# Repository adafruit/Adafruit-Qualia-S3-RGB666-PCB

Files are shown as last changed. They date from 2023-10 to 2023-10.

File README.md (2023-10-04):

## Adafruit Qualia ESP32-S3 for TTL RGB-666 Displays PCB

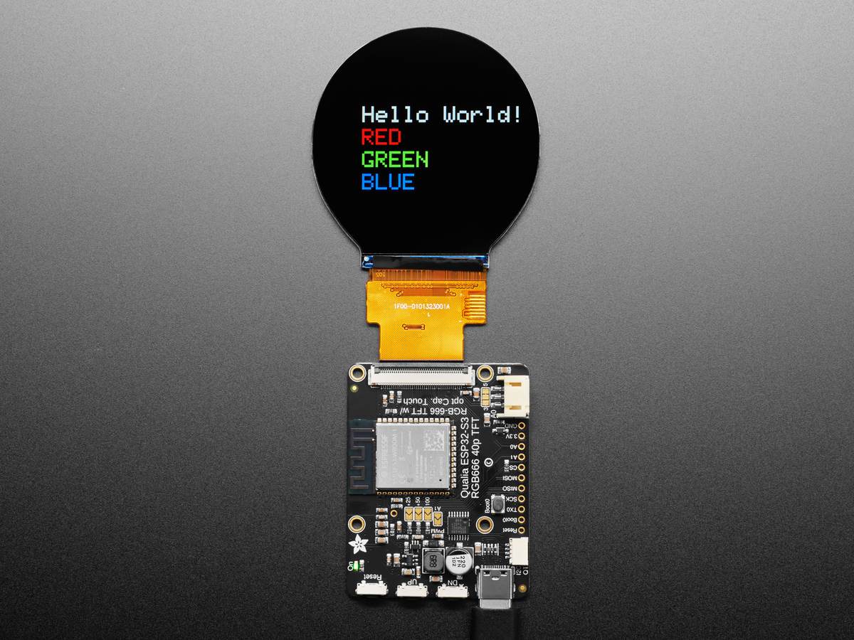
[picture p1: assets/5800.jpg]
<a href="http://www.adafruit.com/products/5800"><br/>
Click here to purchase one from the Adafruit shop</a>

PCB files for the Adafruit Qualia ESP32-S3 for TTL RGB-666 Displays.

Format is EagleCAD schematic and board layout
* https://www.adafruit.com/product/5800

### Description

There's a few things everyone loves: ice cream, kittens, and honkin' large TFT screens. We're no strangers to small TFT's - [from our itsy 1.14" color display](https://www.adafruit.com/search?q=1.14+tft) that graces many-a-TFT-Feather to [our fancy 3.5" 320x480](https://www.adafruit.com/product/2050) breakout screen. But most people who dabble or engineer with microcontrollers know that you sort of 'top out' at 320x480 - that's the largest resolution you can use with every day SPI or 8-bit 8080 interfaces. After that, you're in TTL-interface TFT land, where displays no longer have an internal memory buffer and instead the controller has to continuously write scanline data over a 16 or 18 or 24 pin interface.

RGB TTL interface TFT displays can get big: they start out at around 4.3" diagonal 480x272, and can get to 800x480, 800x600 or even 720x720. For displays that big, you need a lot of video RAM (800x480 at 24 bit color is just over 1MB), plenty of spare GPIO to dedicate, and a peripheral that will DMA the video RAM out to the display continuously. This is a setup familiar to people working with hefty microcontrollers or microcomputers, the sort of device that run cell phones, or your car's GPS navigation screen. But until now, nearly impossible to use on low cost microcontrollers.

The ESP32-S3 is the first low-cost microcontroller that has a built in peripheral that can drive TTL displays, and can come with enough PSRAM to buffer those large images. For example, on the **Adafruit Qualia ESP32-S3 for TTL RGB-666 Displays**, we use a S3 module with 16 MB of Flash and 8 MB of octal PSRAM. Using the built in RGB display peripheral you can display graphics, images, animations or even video (cinepak, natch!) with near-instantaneous updates since the whole screen gets updated every ~30FPS.

This dev board is designed to make it easy for you to explore displays that use the "secondary standard' 40-pin RGB-666 connector. This pin order is most commonly seen on square, round and bar displays. [You'll want to compare the display you're using to this datasheet](https://cdn-shop.adafruit.com/product-files/5792/Specification_TL021WVC02CT-B1323B.pdf), if it matches you'll probably be good! One nice thing about this connector ordering is that it also includes pins for capacitive touch overlay, and we wire those up to the ESP32-S3's I2C port so you can also have touch control with your display.

**Don't forget! This is just the development board, a display is not included.** Use any RGB-666 pinout display with or without a touch overlay. Note that you will need to program in the driver initialization code, dimensions, and pulse widths in your programming language. Here are some known-working displays that you can use in Arduino or CircuitPython:

- [2.1" 480x480 Round with Capacitive Touch](https://www.adafruit.com/product/5792)
- [2.1" 480x480 Round without touch](https://www.adafruit.com/product/5806)
- [4" 720x720 Square with Capacitive Touch](https://www.adafruit.com/product/5794)
- [4" 720x720 Round without touch](https://www.adafruit.com/product/5793)
- [4.6" 960x320 Rectangular Bar](https://www.adafruit.com/product/5805)

On the Qualia board we have the S3 modules, with 16 pins connected to the TFT for 5-6-5 RGB color, plus HSync, VSync, Data Enable and Pixel Clock. There's a constant current backlight control circuit using the [TPS61169](https://www.ti.com/product/TPS61169/part-details/TPS61169DCKR) which can get up to 30V forward voltage and can be configured for 25mA-200mA in 25mA increments (default is 25mA). Power and programming is provided over a USB C connector, wired to the S3's native USB port. For debugging, the hardware UART TX pin is available as well.

Since almost every GPIO is used, and almost all RGB-666 displays need to be initialized over SPI, we put a [PCA9554](https://www.ti.com/product/PCA9554) I/O expander on the shared I2C bus. Arduino or CircuitPython can be instructed on how to use the expander to reset and init the display you have if necessary. The remaining expander pins are connected to two right-angle buttons, and the display backlight.

The expander is what lets us have a full 4-pin SPI port and two more analog GPIO pins - [enough to wire up an MMC in 1-wire SDIO mode along with an I2S amplifier to make an A/V playback demo](https://www.youtube.com/watch?v=pEjw-bCQ-lQ). Maybe we can even eat ice cream while watching kitten vids! There is also the shared I2C port, we provide a Stemma QT / Qwiic port for easy addition of any sensor or device you like.

### License

Adafruit invests time and resources providing this open source design, please support Adafruit and open-source hardware by purchasing products from [Adafruit](https://www.adafruit.com)!

Designed by Limor Fried/Ladyada for Adafruit Industries.

Creative Commons Attribution/Share-Alike, all text above must be included in any redistribution.
See license.txt for additional details.

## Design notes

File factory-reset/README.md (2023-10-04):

## Factory Reset file - Qualia ESP32-S3 for TTL RGB-666 Displays

This is the factory reset file for the Qualia ESP32-S3 for TTL RGB-666 Displays.

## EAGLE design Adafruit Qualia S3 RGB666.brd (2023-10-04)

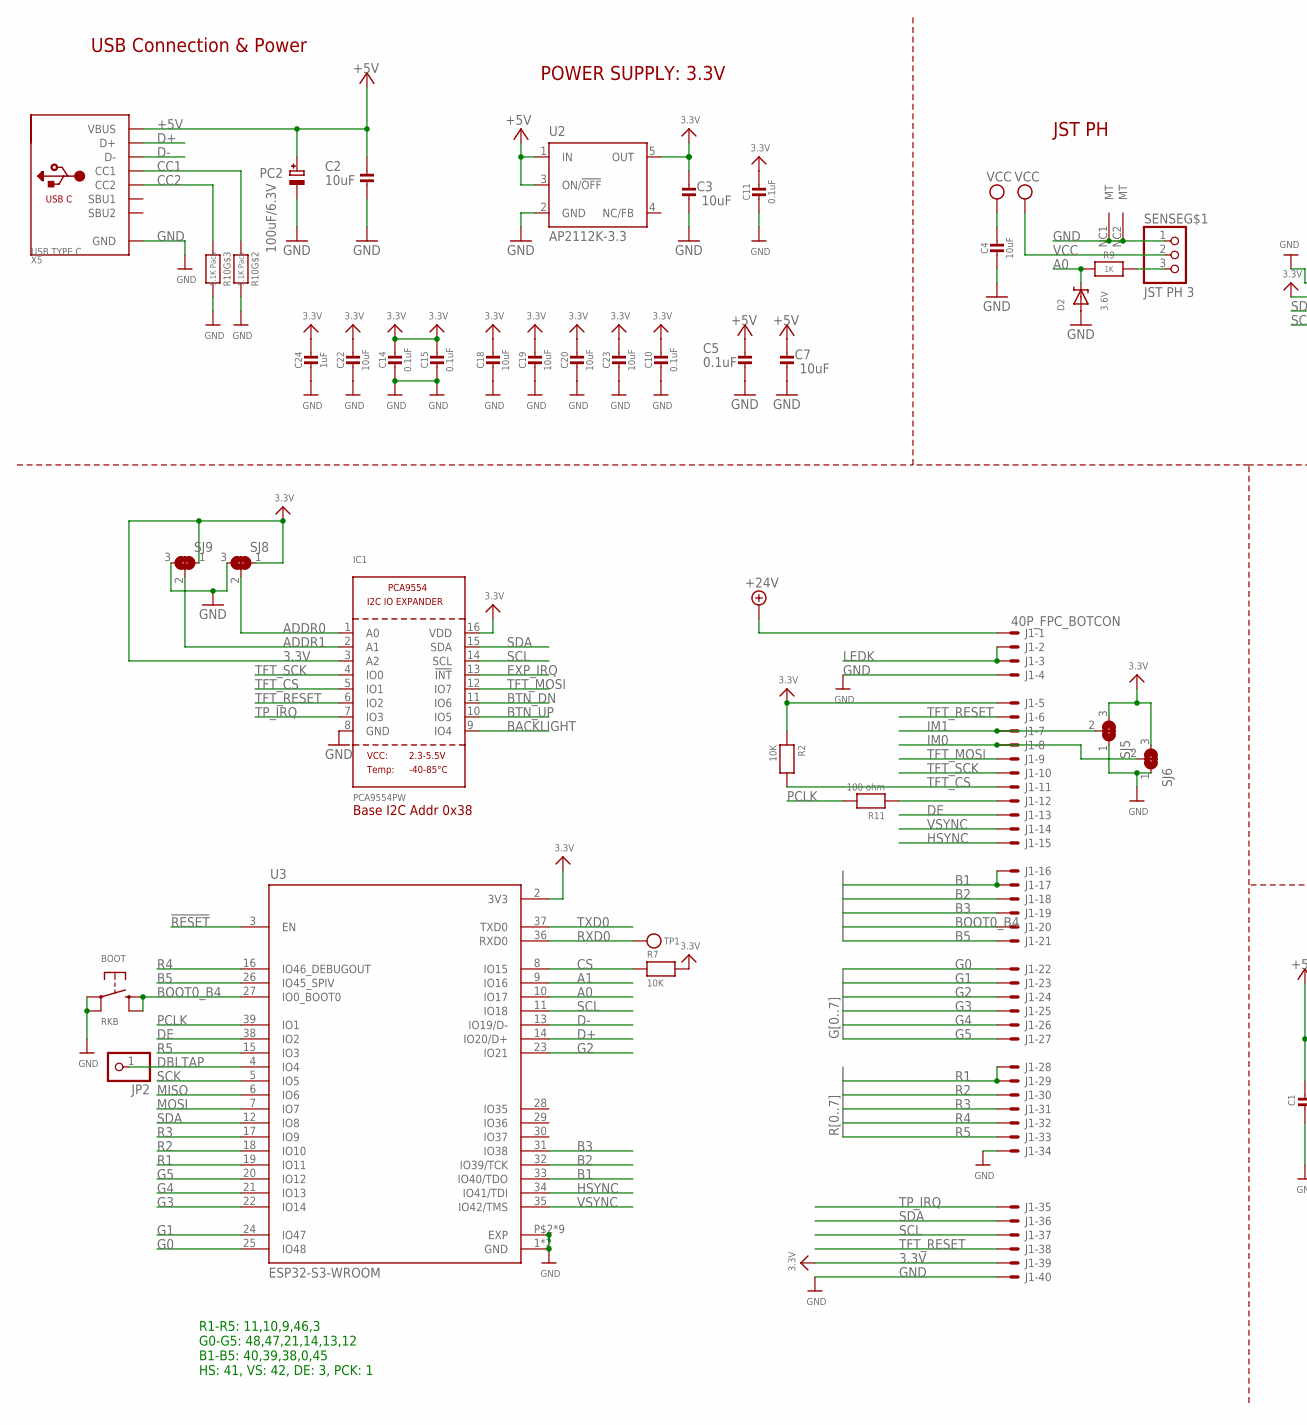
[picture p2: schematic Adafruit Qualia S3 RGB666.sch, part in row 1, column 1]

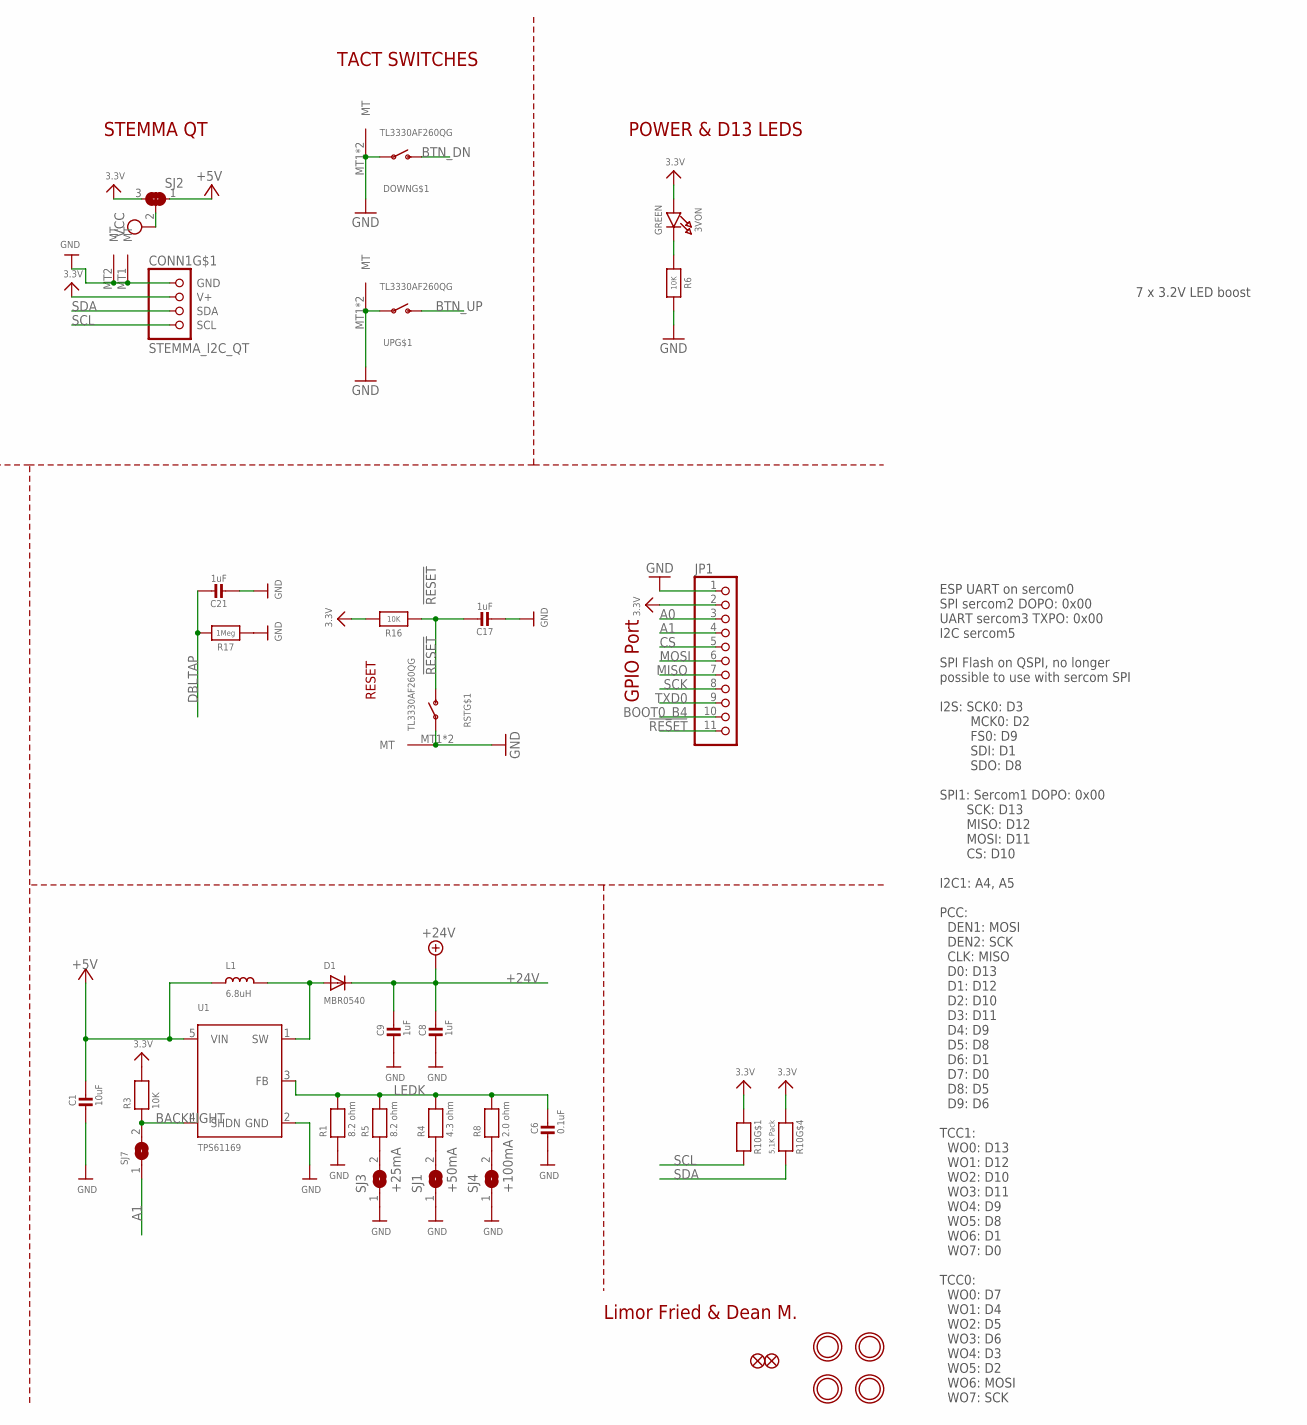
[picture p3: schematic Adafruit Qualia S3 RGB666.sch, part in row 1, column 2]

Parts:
3VON: GREEN; CHIPLED_0603_NOOUTLINE
BOOT: RKB; BTN_RKB2_4.6X2.8
C1, C2, C3, C4, C7, C18, C19, C20, C22, C23: 10uF; 0805-NO
C5, C6, C10, C11, C14, C15: 0.1uF; 0603-NO
C8, C9, C17, C21, C24: 1uF; 0603-NO
CONN1: STEMMA_I2C_QT; JST_SH4
D1: MBR0540; SOD-123
D2: 3.6V; SOD-323
DOWN: TL3330AF260QG; SPST_TACTILE_RA
FID1, FID2: FIDUCIAL_1MM
IC1: PCA9554PW; TSSOP16
J1: 40P_FPC_BOTCON; FPC_40
JP1: HEADER-1X11; 1X11_ROUND
JP2: HEADER-1X1ROUND; 1X01_ROUND
L1: 6.8uH; INDUCTOR_5X5MM_NR5040_NOTHERMALS
PC2: 100uF/6.3V; PANASONIC_D
R1, R5: 8.2 ohm; 0603-NO
R2, R3, R6, R7, R16: 10K; 0603-NO
R4: 4.3 ohm; 0603-NO
R8: 2.0 ohm; 0603-NO
R9: 1K; 0603-NO
R10: 5.1K Pack; RESPACK_4X0603
R11: 100 ohm; 0603-NO
R17: 1Meg; 0603-NO
RST: TL3330AF260QG; SPST_TACTILE_RA
SENSE: JST PH 3; JSTPH3
SJ1: +50mA; SOLDERJUMPER_ARROW_NOPASTE
SJ2, SJ5, SJ6, SJ8, SJ9: SOLDERJUMPER_2WAY; SOLDERJUMPER_2WAY_OPEN_NOPASTE
SJ3: +25mA; SOLDERJUMPER_ARROW_NOPASTE
SJ4: +100mA; SOLDERJUMPER_ARROW_NOPASTE
SJ7: SOLDERJUMPER; SOLDERJUMPER_ARROW_NOPASTE
TP1: TESTPOINTROUND1.5MMNO; TESTPOINT_ROUND_1.5MM_NO
U1: TPS61169; SC70-5
U2: AP2112K-3.3; SOT23-DBV
U3: ESP32-S3-WROOM; S3-WROOM32
U$14, U$19, U$22, U$24: MOUNTINGHOLE2.5; MOUNTINGHOLE_2.5_PLATED
UP: TL3330AF260QG; SPST_TACTILE_RA
X5: USB TYPE C; USB_C_CUSB31-CFM2AX-01-X

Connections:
3.3V: 3VON.A, C3.2, C10.2, C11.2, C14.2, C15.2, C18.1, C19.1, C20.1, C22.1, C23.1, C24.1, CONN1.2 (V+), IC1.3 (A2), IC1.16 (VDD), J1.5 (MS), J1.39 (MS), JP1.2, R2.1, R3.2, R7.2, R10.1, R10.4 (1), R16.2, SJ2.3, SJ5.3, SJ6.3, SJ8.1, SJ9.1, U2.5 (OUT), U3.2 (3V3)
!RESET: C17.1, JP1.11, R16.1, RST.2 (S), U3.3 (EN)
+5V: C1.1, C2.2, C5.2, C7.2, L1.P$1 (1), PC2.+, SJ2.1, U1.5 (VIN), U2.1 (IN), U2.3 (ON/!OFF), X5.A4B9 (VBUS), X5.B4A9 (VBUS)
+24V: C8.1, C9.1, D1.C, J1.1 (MSV)
A0: D2.C, JP1.3, R9.2, U3.10 (IO17)
A0_JST: R9.1, SENSE.3
A1: JP1.4, SJ7.1, U3.9 (IO16)
ADDR0: IC1.1 (A0), SJ8.2
ADDR1: IC1.2 (A1), SJ9.2
B1: J1.16 (MS), J1.17 (MS), U3.33 (IO40/TDO)
B2: J1.18 (MS), U3.32 (IO39/TCK)
B3: J1.19 (MS), U3.31 (IO38)
B5: J1.21 (MS), U3.26 (IO45_SPIV)
BACKLIGHT: IC1.9 (IO4), R3.1, SJ7.2, U1.4 (SHDN)
BOOT0_B4: BOOT.B (S), BOOT.B' (S1), J1.20 (MS), JP1.10, U3.27 (IO0_BOOT0)
BTN_DN: DOWN.2 (S), IC1.11 (IO6)
BTN_UP: IC1.10 (IO5), UP.2 (S)
CC1: R10.2 (1), X5.A5 (CC1)
CC2: R10.3 (1), X5.B5 (CC2)
CS: JP1.5, R7.1, U3.8 (IO15)
D+: U3.14 (IO20/D+), X5.A6 (D+), X5.B6 (D+)
D-: U3.13 (IO19/D-), X5.A7 (D-), X5.B7 (D-)
DBLTAP: C21.1, JP2.1, R17.2, U3.4 (IO4)
DE: J1.13 (MS), U3.38 (IO2)
EXP_IRQ: IC1.13 (!INT)
G0: J1.22 (MS), U3.25 (IO48)
G1: J1.23 (MS), U3.24 (IO47)
G2: J1.24 (MS), U3.23 (IO21)
G3: J1.25 (MS), U3.22 (IO14)
G4: J1.26 (MS), U3.21 (IO13)
G5: J1.27 (MS), U3.20 (IO12)
GND: BOOT.A, BOOT.A' (P1), C1.2, C2.1, C3.1, C4.2, C5.1, C6.2, C7.1, C8.2, C9.2, C10.1, C11.1, C14.1, C15.1, C17.2, C18.2, C19.2, C20.2, C21.2, C22.2, C23.2, C24.2, CONN1.1 (GND), CONN1.MT1 (MT), CONN1.MT2 (MT), D2.A, DOWN.1, DOWN.MT1 (MT), DOWN.MT2 (MT), IC1.8 (GND), J1.4 (MS), J1.34 (MS), J1.40 (MS), JP1.1, PC2.-, R1.1, R6.2, R10.6 (2), R10.7 (2), R17.1, RST.1, RST.MT1 (MT), RST.MT2 (MT), SENSE.1, SENSE.NC1 (MT), SENSE.NC2 (MT), SJ1.1, SJ3.1, SJ4.1, SJ5.1, SJ6.1, SJ8.3, SJ9.3, U1.2 (GND), U2.2 (GND), U3.1 (GND), U3.40 (GND), U3.P$2 (EXP), U3.P$3 (EXP), U3.P$4 (EXP), U3.P$5 (EXP), U3.P$6 (EXP), U3.P$7 (EXP), U3.P$8 (EXP), U3.P$9 (EXP), U3.P$10 (EXP), UP.1, UP.MT1 (MT), UP.MT2 (MT), X5.A1B12 (GND), X5.B1A12 (GND)
HSYNC: J1.15 (MS), U3.34 (IO41/TDI)
IM0: J1.8 (MS), SJ6.2
IM1: J1.7 (MS), SJ5.2
LEDK: C6.1, J1.2 (MS), J1.3 (MS), R1.2, R4.2, R5.2, R8.2, U1.3 (FB)
MISO: JP1.7, U3.6 (IO6)
MOSI: JP1.6, U3.7 (IO7)
unnamed: 3VON.C, R6.1
unnamed: R4.1, SJ1.2
unnamed: J1.12 (MS), R11.1
unnamed: D1.A, L1.P$2 (2), U1.1 (SW)
unnamed: R5.1, SJ3.2
unnamed: R8.1, SJ4.2
PCLK: R11.2, U3.39 (IO1)
R1: J1.28 (MS), J1.29 (MS), U3.19 (IO11)
R2: J1.30 (MS), U3.18 (IO10)
R3: J1.31 (MS), U3.17 (IO9)
R4: J1.32 (MS), U3.16 (IO46_DEBUGOUT)
R5: J1.33 (MS), U3.15 (IO3)
RXD0: TP1.P$1, U3.36 (RXD0)
SCK: JP1.8, U3.5 (IO5)
SCL: CONN1.4 (SCL), IC1.14 (SCL), J1.37 (MS), R10.8 (2), U3.11 (IO18)
SDA: CONN1.3 (SDA), IC1.15 (SDA), J1.36 (MS), R10.5 (2), U3.12 (IO8)
TFT_CS: IC1.5 (IO1), J1.11 (MS), R2.2
TFT_MOSI: IC1.12 (IO7), J1.9 (MS)
TFT_RESET: IC1.6 (IO2), J1.6 (MS), J1.38 (MS)
TFT_SCK: IC1.4 (IO0), J1.10 (MS)
TP_IRQ: IC1.7 (IO3), J1.35 (MS)
TXD0: JP1.9, U3.37 (TXD0)
VCC: C4.1, SENSE.2, SJ2.2
VSYNC: J1.14 (MS), U3.35 (IO42/TMS)

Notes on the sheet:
Limor Fried & Dean M.
USB Connection & Power
POWER SUPPLY: 3.3V
POWER & D13 LEDS
GPIO Port
ESP UART on sercom0 SPI sercom2 DOPO: 0x00 UART sercom3 TXPO: 0x00 I2C sercom5 SPI Flash on QSPI, no longer possible to use with sercom SPI I2S: SCK0: D3 MCK0: D2 FS0: D9 SDI: D1 SDO: D8 SPI1: Sercom1 DOPO: 0x00 SCK: D13 MISO: D12 MOSI: D11 CS: D10 I2C1: A4, A5 PCC: DEN1: MOSI DEN2: SCK CLK: MISO D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
RESET
JST PH
STEMMA QT
TACT SWITCHES
7 x 3.2V LED boost
Base I2C Addr 0x38
R1-R5: 11,10,9,46,3 G0-G5: 48,47,21,14,13,12 B1-B5: 40,39,38,0,45 HS: 41, VS: 42, DE: 3, PCK: 1

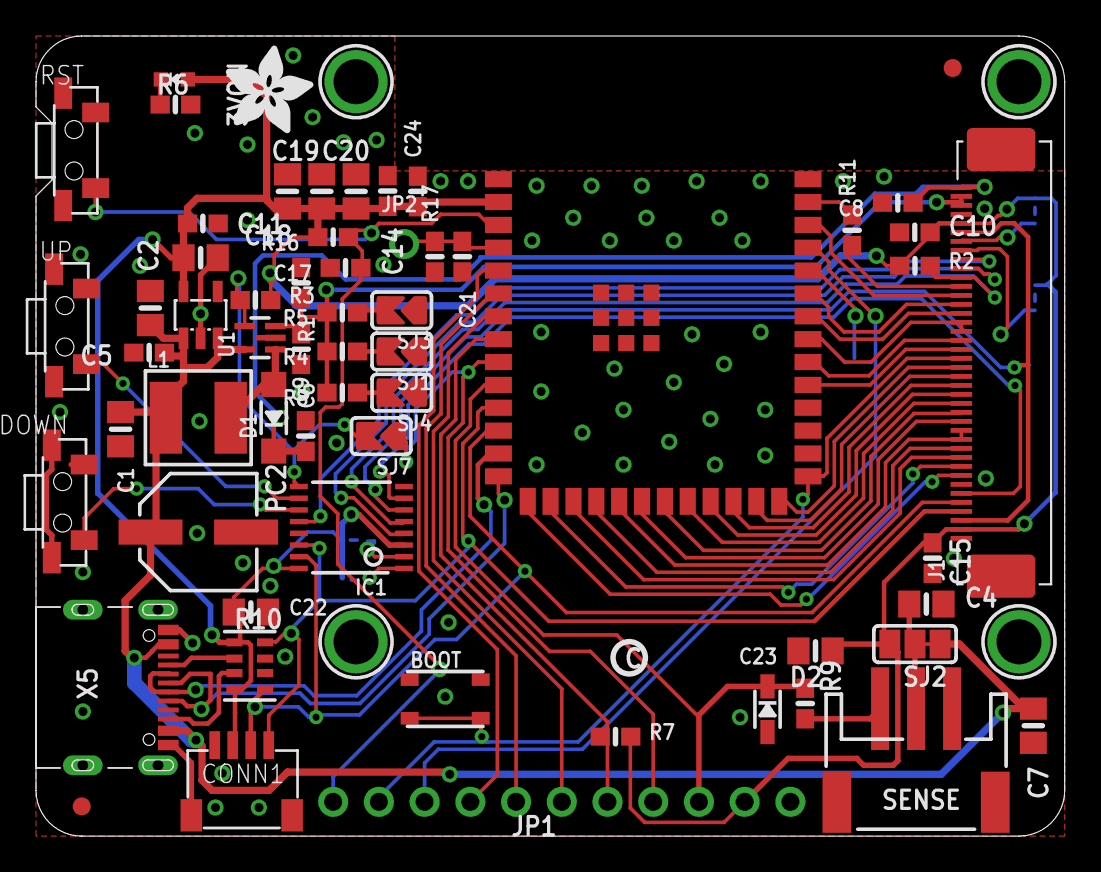
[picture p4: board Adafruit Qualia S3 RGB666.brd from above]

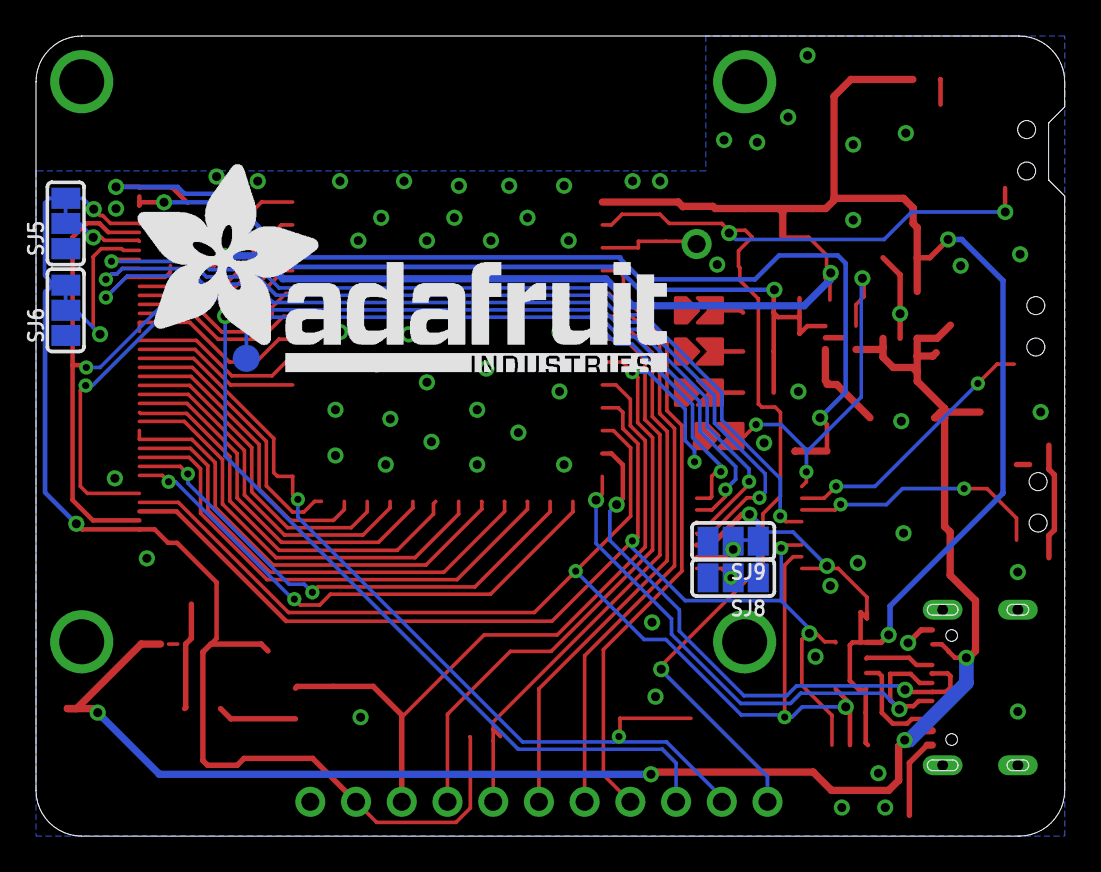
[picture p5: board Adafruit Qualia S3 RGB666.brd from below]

Board: 2 copper layers, 57.1 x 44.5 mm, 112 parts (19 on the bottom side), 61 nets.

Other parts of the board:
PLABEL0: PLABEL0
PLABEL1: PLABEL1
PLABEL2: PLABEL2
PLABEL3: PLABEL3
PLABEL4: PLABEL4
PLABEL5: PLABEL5
PLABEL6: PLABEL6
PLABEL7: PLABEL7
PLABEL8: PLABEL8
PLABEL9: PLABEL9
PLABEL10: PLABEL10
PLABEL11: PLABEL11
PLABEL12: PLABEL12
PLABEL13: PLABEL13
PLABEL14: PLABEL14
PLABEL15: PLABEL15
PLABEL16: PLABEL16
PLABEL17: PLABEL17
PLABEL18: PLABEL18
PLABEL19: PLABEL19
PLABEL20: PLABEL20
PLABEL21: PLABEL21
PLABEL22: PLABEL22
PLABEL23: PLABEL23
PLABEL24: PLABEL24
PLABEL25: PLABEL25
PLABEL26: PLABEL26
PLABEL27: PLABEL27
PLABEL28: PLABEL28
PLABEL29: PLABEL29
PLABEL30: PLABEL30
PLABEL31: PLABEL31
PLABEL32: PLABEL32
PLABEL33: PLABEL33
PLABEL34: PLABEL34
PLABEL35: PLABEL35
PLABEL36: PLABEL36
PLABEL37: PLABEL37
PLABEL38: PLABEL38
PLABEL39: PLABEL39
U$44: PCBFEAT-REV-040
U$46: ADAFRUIT_5MM
U$49: ADAFRUIT_TEXT_30MM

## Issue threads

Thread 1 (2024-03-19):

PCA9555 interrupt pin not connected

mobileoverlord, 2024-03-19:
Hello, I was curious on a design decision for this board. The PCA9555 GPIO expander doesn't wire up the interrupt pin (pin 13) to the ESP32-S3. I find this odd especially since the display interrupt is wired to this expander as well as the user buttons on the board. Looks like it would be pretty straight forward to connect this to pin 30 on the ESP32. Thanks!

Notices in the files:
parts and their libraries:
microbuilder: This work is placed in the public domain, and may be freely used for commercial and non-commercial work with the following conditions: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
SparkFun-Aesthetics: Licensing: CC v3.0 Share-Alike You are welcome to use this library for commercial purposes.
